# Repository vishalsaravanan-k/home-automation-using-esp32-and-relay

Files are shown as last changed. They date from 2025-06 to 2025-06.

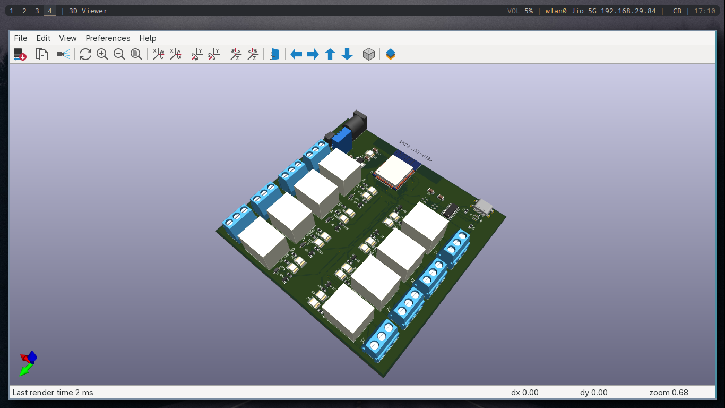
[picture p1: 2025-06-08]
Images/8.png

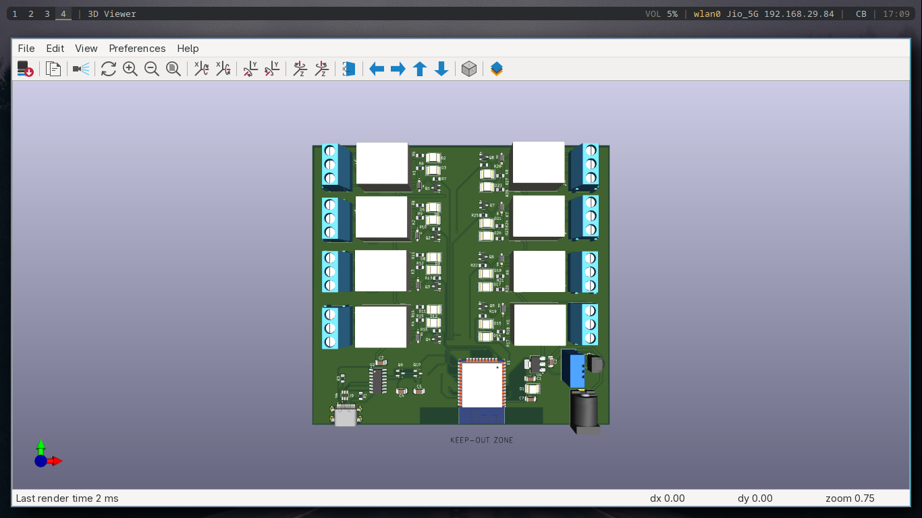
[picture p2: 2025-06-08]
Images/5.png

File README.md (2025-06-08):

# 🏠 Home Automation using ESP32 with relay

This project is a basic **home automation system** built using an **ESP32**, capable of turning appliances **ON/OFF** through both **mobile app (via Wi-Fi)** and an **IR remote**. It is designed for beginners in IoT and embedded systems who want to automate devices like lights, fans, or other home appliances.

---

## 📦 Features
- ✅ Control appliances via **Wi-Fi** (mobile app/web interface)
- ✅ Support for **IR remote control** using TSOP1838 sensor
- ✅ 8-channel relay circuit for switching multiple devices
- ✅ Designed using **KiCad** and built around **ESP32-WROOM-32**
- ✅ USB-C interface with ESD protection and CH340 serial converter
- ✅ Power supply using AMS1117-3.3

---

## 🧰 Hardware Components
- ESP32-WROOM-32
- CH340C (USB to serial)
- 8 x Relays (5V)
- 8 x BC547 Transistors
- Diodes (1N4007), LEDs, Resistors
- TSOP1838 IR Receiver
- USB-C Connector
- AMS1117-3.3 Voltage Regulator

---

## 🚀 How It Works
1. ESP32 receives **IR commands** from a remote via TSOP1838.
2. Or, it receives **commands over Wi-Fi** from a mobile/web app.
3. Based on the command, the ESP32 toggles one of the 8 relay channels.
4. Each relay can be connected to an AC appliance to turn it ON or OFF.

---

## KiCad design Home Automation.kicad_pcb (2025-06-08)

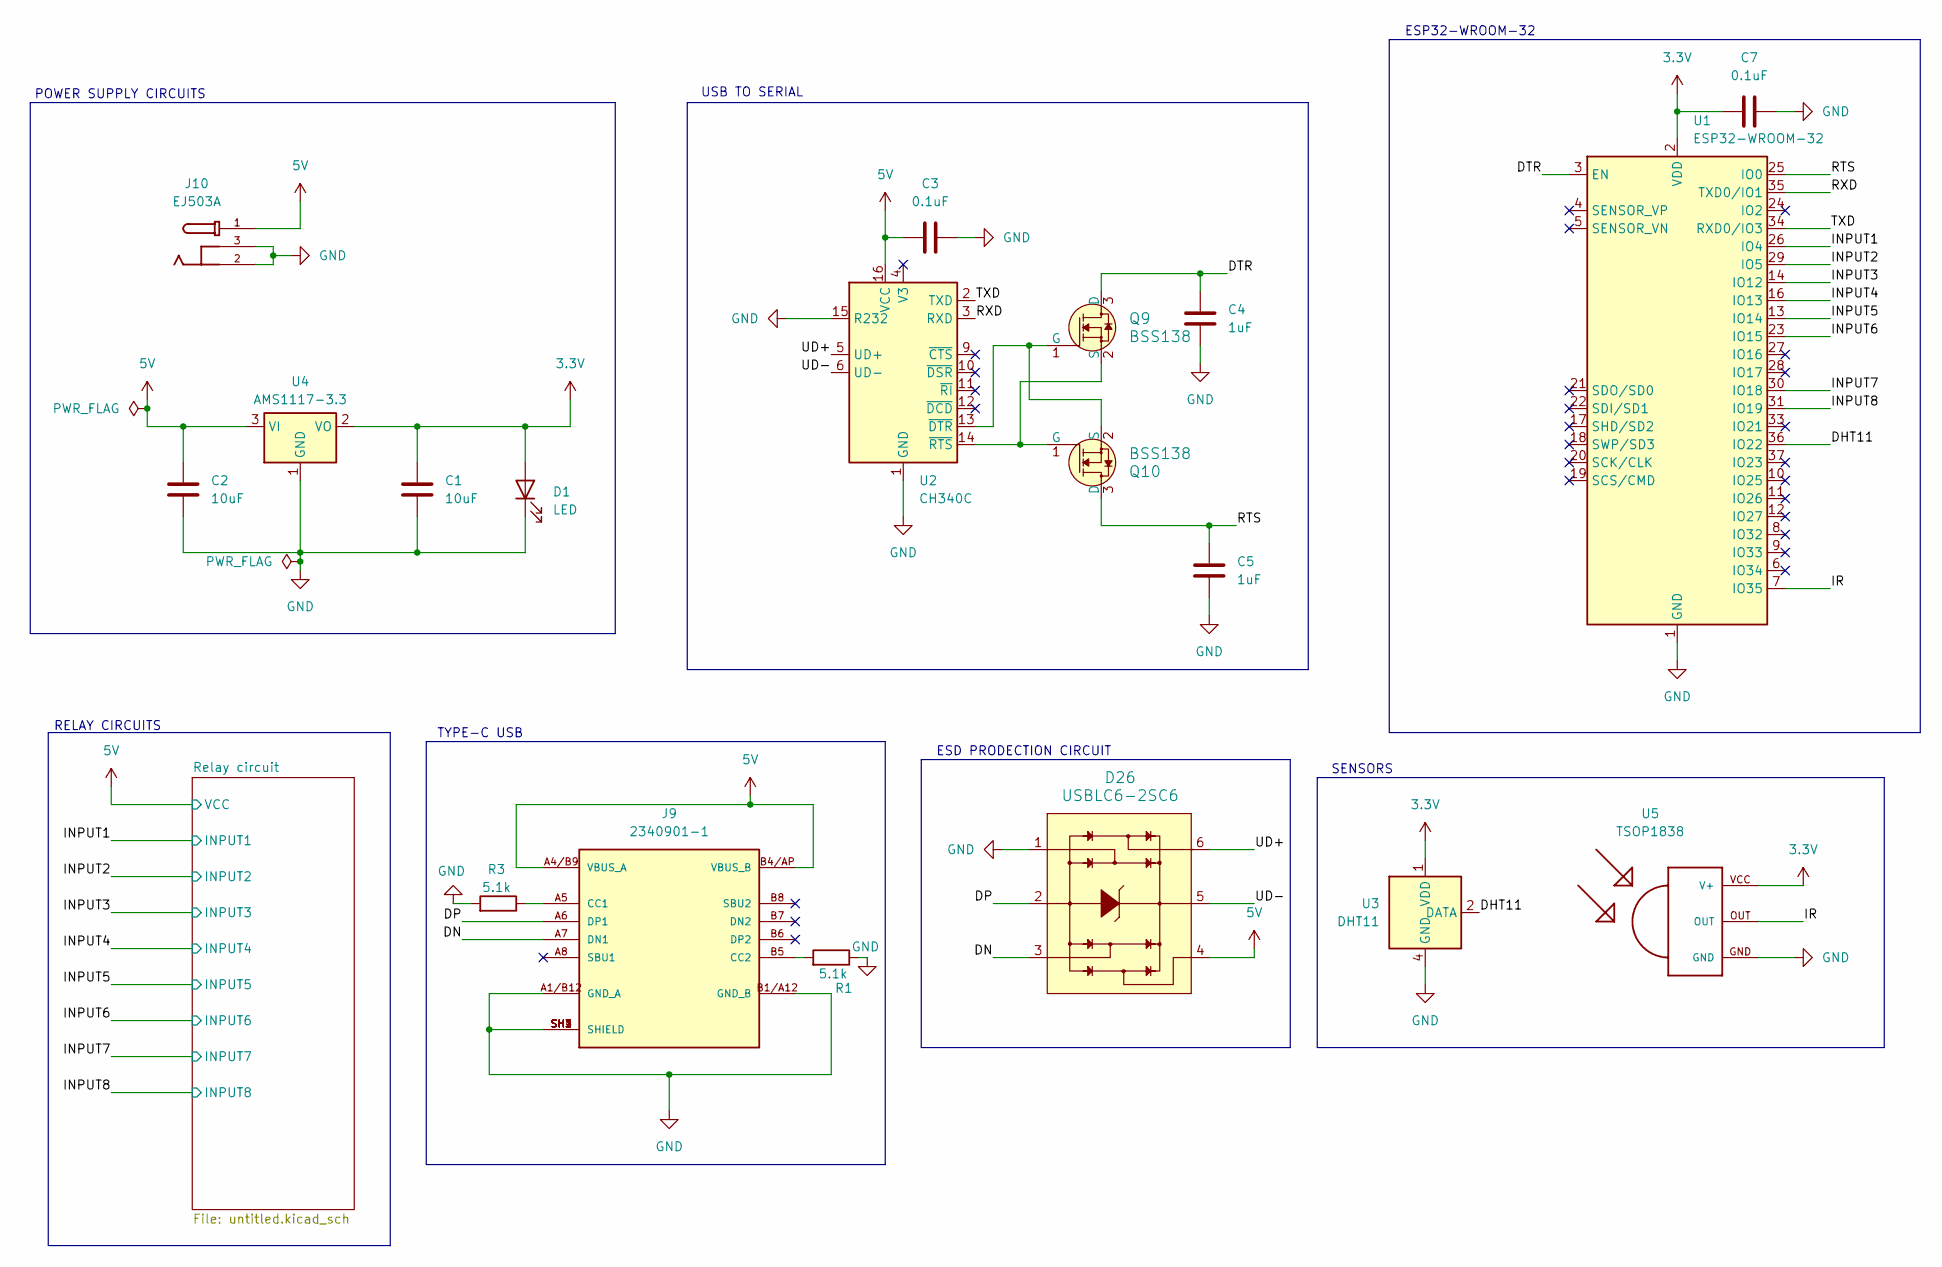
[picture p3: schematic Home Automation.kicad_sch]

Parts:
C1, C2: 10uF; C_1206_3216Metric_Pad1.33x1.80mm_HandSolder
C3, C7: 0.1uF; C_1206_3216Metric_Pad1.33x1.80mm_HandSolder
C4, C5: 1uF; C_1206_3216Metric_Pad1.33x1.80mm_HandSolder
D1: LED; LED_1812_4532Metric_Pad1.30x3.40mm_HandSolder
D26: USBLC6-2SC6; SOT95P280X145-6N; MPN USBLC6-2SC6; Digi-Key_PN 497-5235-1-ND
J9: 2340901-1; TE_2340901-1; PARTREV A
J10: EJ503A; MPD_EJ503A; PARTREV B
Q9, Q10: BSS138; SOT-23-3; MPN BSS138; Digi-Key_PN BSS138CT-ND
R1, R3: 5.1k; R_0805_2012Metric_Pad1.20x1.40mm_HandSolder
U1: ESP32-WROOM-32
U2: CH340C; SOIC-16_3.9x9.9mm_P1.27mm
U3: DHT11; Aosong_DHT11_5.5x12.0_P2.54mm
U4: AMS1117-3.3; SOT-223-3_TabPin2
U5: TSOP1838; TSOP18XX

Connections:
3.3V: C1.1, C7.1, D1.2 (A), U1.2 (VDD), U3.1 (VDD), U4.2 (VO), U5.VCC (V+)
5V: C2.1, C3.1, D26.4, J9.A4/B9 (VBUS_A), J9.B4/AP (VBUS_B), J10.1, U2.16 (VCC), U4.3 (VI); also elsewhere on the board
/DHT11: U1.36 (IO22), U3.2 (DATA)
/DN: D26.3, J9.A7 (DN1)
/DP: D26.2, J9.A6 (DP1)
/DTR: C4.2, Q9.3 (D), U1.3 (EN)
/INPUT1: U1.26 (IO4); also elsewhere on the board
/INPUT2: U1.29 (IO5); also elsewhere on the board
/INPUT3: U1.14 (IO12); also elsewhere on the board
/INPUT4: U1.16 (IO13); also elsewhere on the board
/INPUT5: U1.13 (IO14); also elsewhere on the board
/INPUT6: U1.23 (IO15); also elsewhere on the board
/INPUT7: U1.30 (IO18); also elsewhere on the board
/INPUT8: U1.31 (IO19); also elsewhere on the board
/IR: U1.7 (IO35), U5.OUT
/RTS: C5.2, Q10.3 (D), U1.25 (IO0)
/RXD: U1.35 (TXD0/IO1), U2.3 (RXD)
/TXD: U1.34 (RXD0/IO3), U2.2 (TXD)
/UD+: D26.6, U2.5 (UD+)
/UD-: D26.5, U2.6 (UD-)
GND: C1.2, C2.2, C3.2, C4.1, C5.1, C7.2, D1.1 (K), D26.1, J9.A1/B12 (GND_A), J9.B1/A12 (GND_B), J9.SH1 (SHIELD), J9.SH2 (SHIELD), J9.SH3 (SHIELD), J9.SH4 (SHIELD), J10.2, J10.3, R1.1, R3.2, U1.1 (GND), U1.15 (GND), U1.38 (GND), U1.39 (GND), U2.1 (GND), U2.15 (R232), U3.4 (GND), U4.1 (GND), U5.GND; also elsewhere on the board
unnamed: J9.A5 (CC1), R3.1
unnamed: J9.B5 (CC2), R1.2
unnamed: Q9.2 (S), Q10.1 (G), U2.14 (~RTS)
unnamed: Q9.1 (G), Q10.2 (S), U2.13 (~DTR)

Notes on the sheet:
SENSORS
ESD PRODECTION CIRCUIT
USB TO SERIAL
ESP32-WROOM-32
POWER SUPPLY CIRCUITS
TYPE-C USB
RELAY CIRCUITS

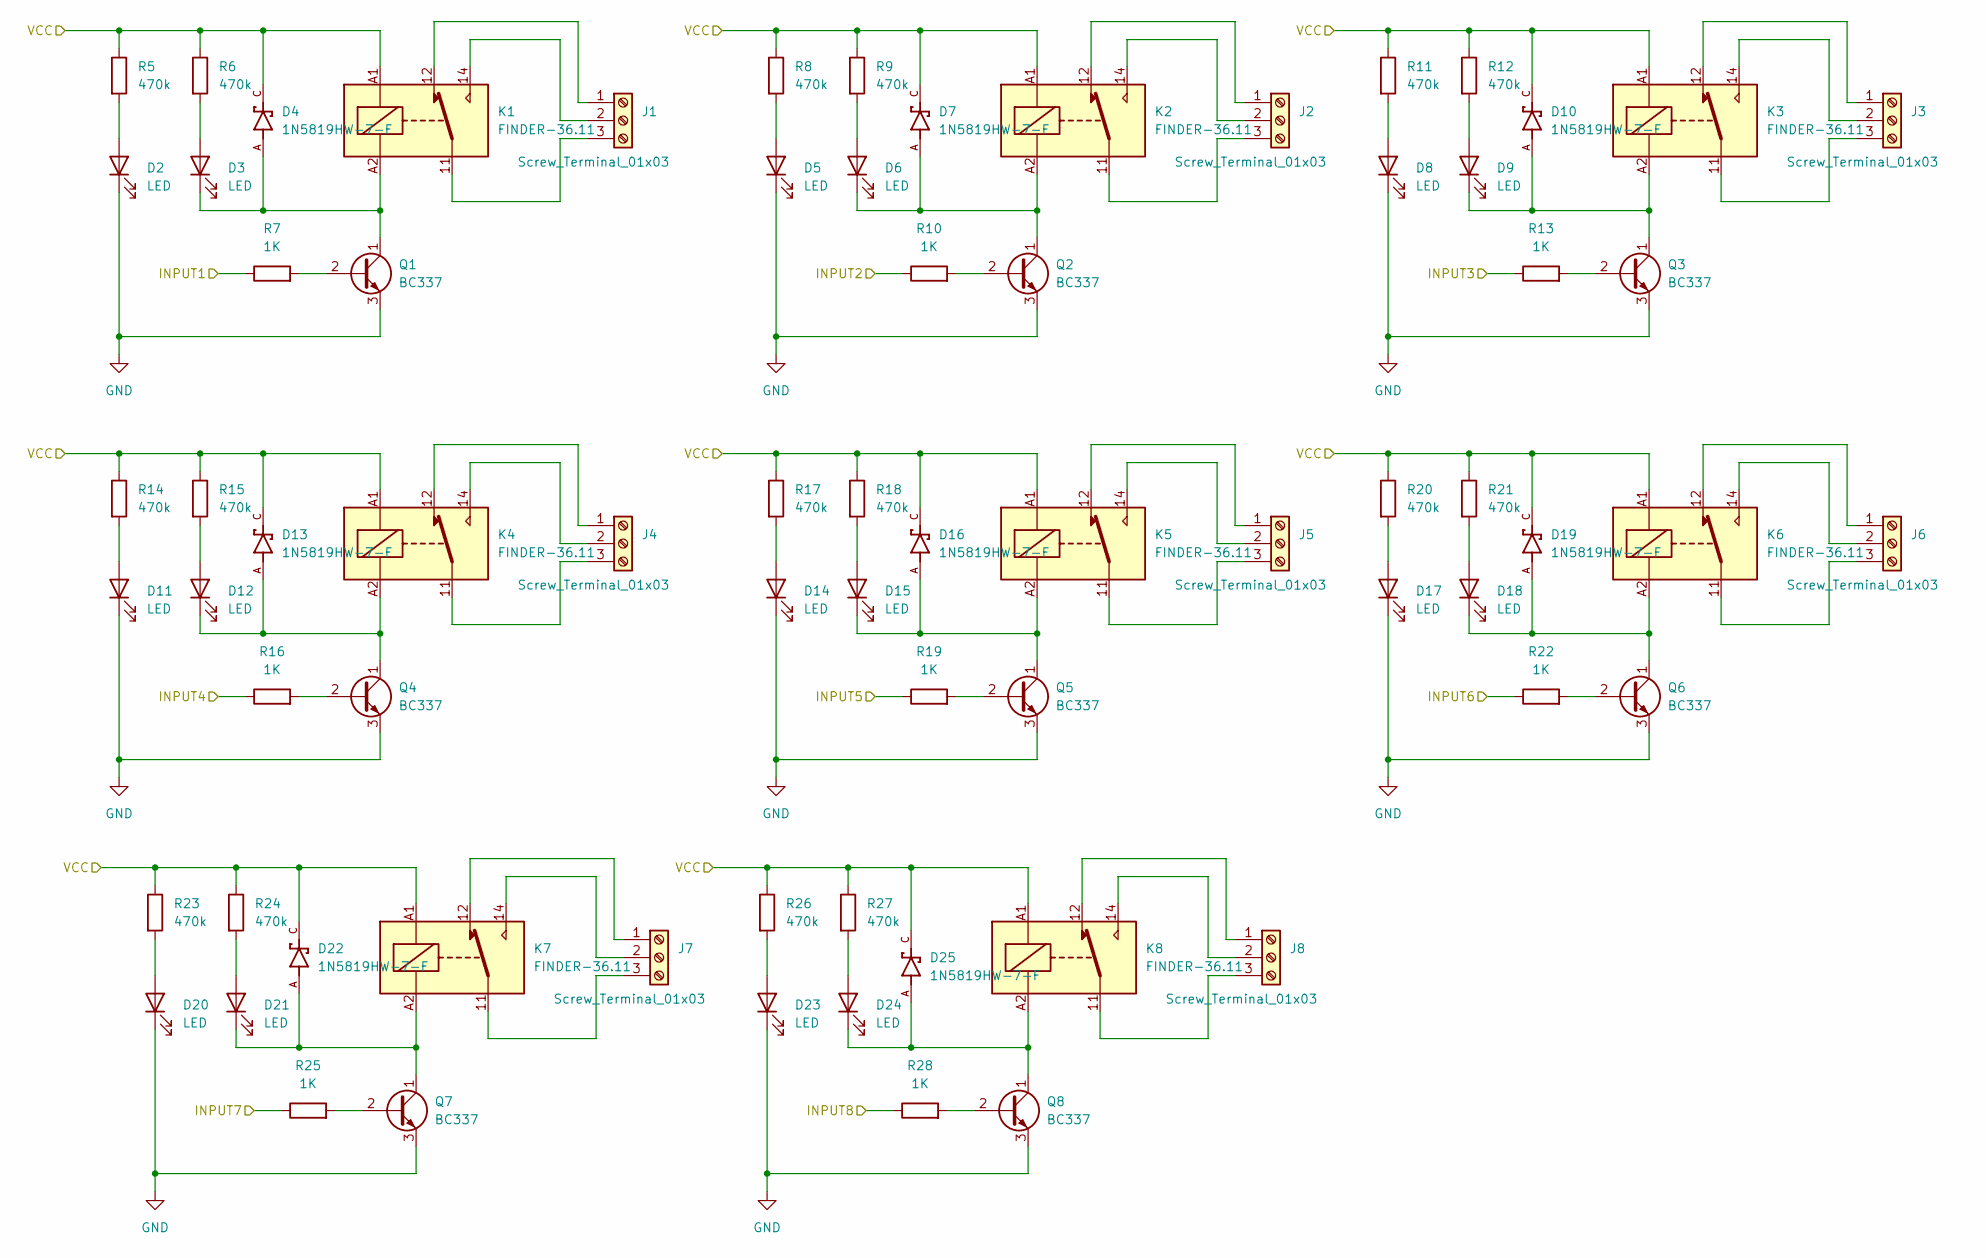
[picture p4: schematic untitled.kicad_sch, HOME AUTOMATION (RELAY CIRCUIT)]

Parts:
D2, D3, D5, D6, D8, D9, D11, D12, D14, D15, D17, D18, D20, D21, D23, D24: LED; LED_1812_4532Metric_Pad1.30x3.40mm_HandSolder
D4, D7, D10, D13, D16, D19, D22, D25: 1N5819HW-7-F; SOD3715X145N; PARTREV 18-2
J1, J2, J3, J4, J5, J6, J7, J8: Screw_Terminal_01x03; CUI_TB004-508-03BE
K1, K2, K3, K4, K5, K6, K7, K8: FINDER-36.11; Relay_SPDT_Finder_36.11
Q1, Q2, Q3, Q4, Q5, Q6, Q7, Q8: BC337; SOT-23-3
R5, R6, R8, R9, R11, R12, R14, R15, R17, R18, R20, R21, R23, R24, R26, R27: 470k; R_0805_2012Metric_Pad1.20x1.40mm_HandSolder
R7, R10, R13, R16, R19, R22, R25, R28: 1K; R_0805_2012Metric_Pad1.20x1.40mm_HandSolder

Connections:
5V: D4.C, D7.C, D10.C, D13.C, D16.C, D19.C, D22.C, D25.C, K1.A1, K2.A1, K3.A1, K4.A1, K5.A1, K6.A1, K7.A1, K8.A1, R5.1, R6.1, R8.1, R9.1, R11.1, R12.1, R14.1, R15.1, R17.1, R18.1, R20.1, R21.1, R23.1, R24.1, R26.1, R27.1; also elsewhere on the board
/INPUT1: R7.1; also elsewhere on the board
/INPUT2: R10.1; also elsewhere on the board
/INPUT3: R13.1; also elsewhere on the board
/INPUT4: R16.1; also elsewhere on the board
/INPUT5: R19.1; also elsewhere on the board
/INPUT6: R22.1; also elsewhere on the board
/INPUT7: R25.1; also elsewhere on the board
/INPUT8: R28.1; also elsewhere on the board
GND: D2.1 (K), D5.1 (K), D8.1 (K), D11.1 (K), D14.1 (K), D17.1 (K), D20.1 (K), D23.1 (K), Q1.3 (E), Q2.3 (E), Q3.3 (E), Q4.3 (E), Q5.3 (E), Q6.3 (E), Q7.3 (E), Q8.3 (E); also elsewhere on the board
unnamed: D2.2 (A), R5.2
unnamed: D3.2 (A), R6.2
unnamed: D3.1 (K), D4.A, K1.A2, Q1.1 (C)
unnamed: D5.2 (A), R8.2
unnamed: D6.2 (A), R9.2
unnamed: D6.1 (K), D7.A, K2.A2, Q2.1 (C)
unnamed: D8.2 (A), R11.2
unnamed: D9.2 (A), R12.2
unnamed: D9.1 (K), D10.A, K3.A2, Q3.1 (C)
unnamed: D11.2 (A), R14.2
unnamed: D12.2 (A), R15.2
unnamed: D12.1 (K), D13.A, K4.A2, Q4.1 (C)
unnamed: D14.2 (A), R17.2
unnamed: D15.2 (A), R18.2
unnamed: D15.1 (K), D16.A, K5.A2, Q5.1 (C)
unnamed: D17.2 (A), R20.2
unnamed: D18.2 (A), R21.2
unnamed: D18.1 (K), D19.A, K6.A2, Q6.1 (C)
unnamed: D20.2 (A), R23.2
unnamed: D21.2 (A), R24.2
unnamed: D21.1 (K), D22.A, K7.A2, Q7.1 (C)
unnamed: D23.2 (A), R26.2
unnamed: D24.2 (A), R27.2
unnamed: D24.1 (K), D25.A, K8.A2, Q8.1 (C)
unnamed: J1.1, K1.12
unnamed: J1.2, K1.14
unnamed: J1.3, K1.11
unnamed: J2.1, K2.12
unnamed: J2.2, K2.14
unnamed: J2.3, K2.11
unnamed: J3.1, K3.12
unnamed: J3.2, K3.14
unnamed: J3.3, K3.11
unnamed: J4.1, K4.12
unnamed: J4.2, K4.14
unnamed: J4.3, K4.11
unnamed: J5.1, K5.12
unnamed: J5.2, K5.14
unnamed: J5.3, K5.11
unnamed: J6.1, K6.12
unnamed: J6.2, K6.14
unnamed: J6.3, K6.11
unnamed: J7.1, K7.12
unnamed: J7.2, K7.14
unnamed: J7.3, K7.11
unnamed: J8.1, K8.12
unnamed: J8.2, K8.14
unnamed: J8.3, K8.11
unnamed: Q1.2 (B), R7.2
unnamed: Q2.2 (B), R10.2
unnamed: Q3.2 (B), R13.2
unnamed: Q4.2 (B), R16.2
unnamed: Q5.2 (B), R19.2
unnamed: Q6.2 (B), R22.2
unnamed: Q7.2 (B), R25.2
unnamed: Q8.2 (B), R28.2

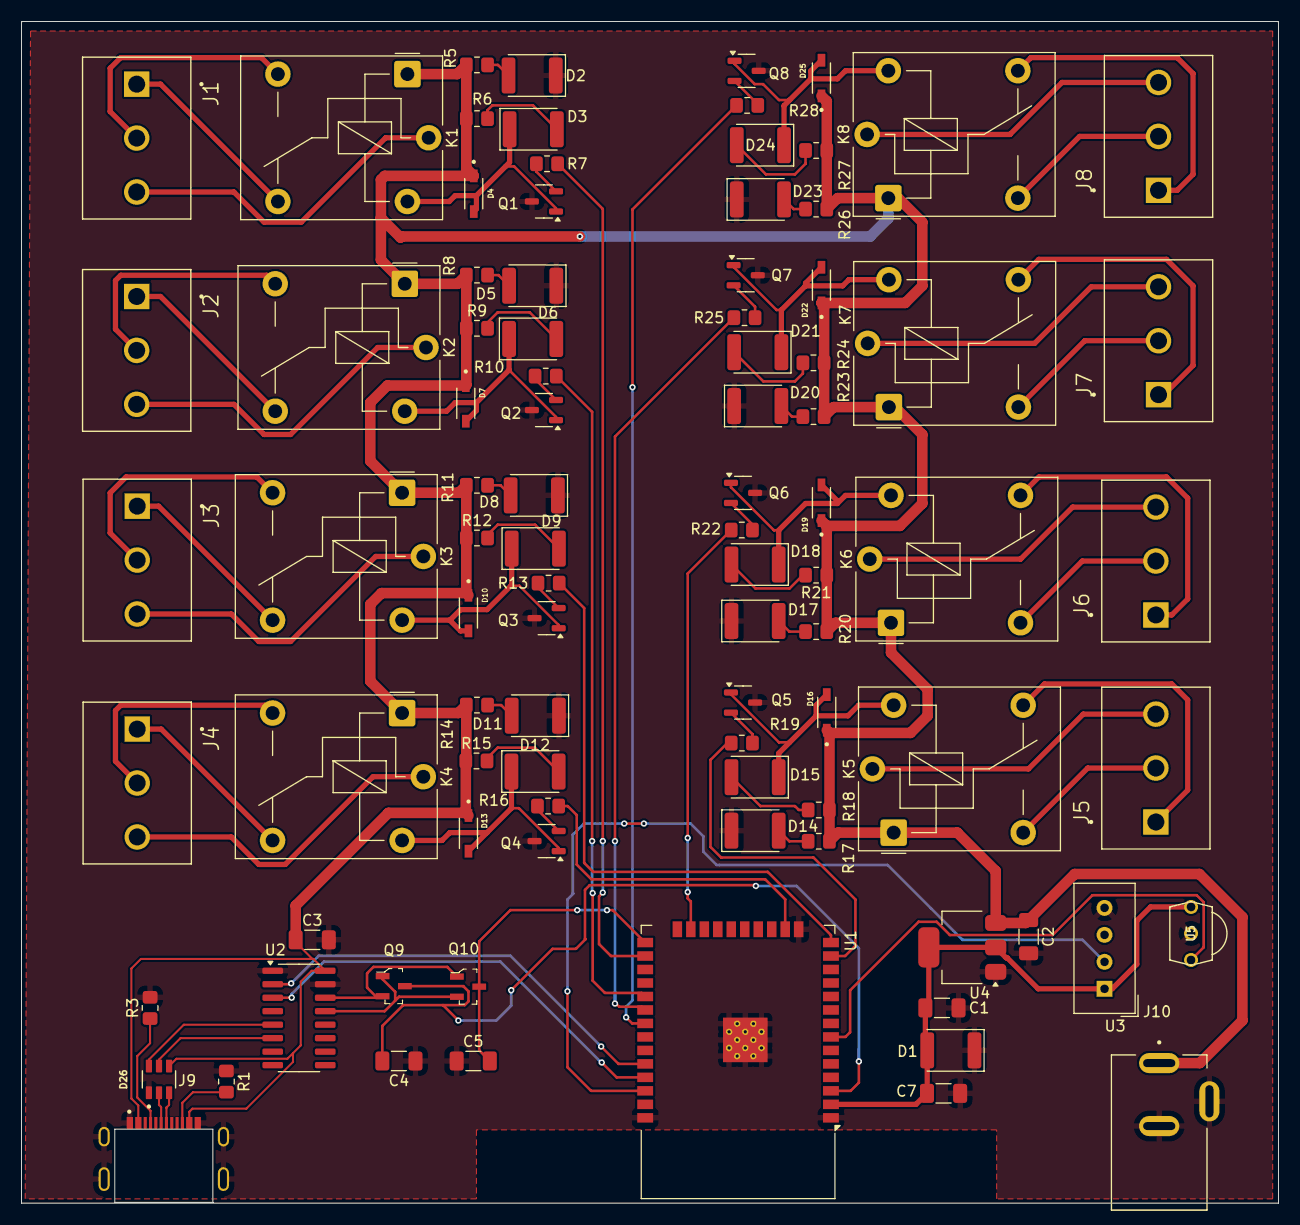
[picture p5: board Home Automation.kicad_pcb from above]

Board: 2 copper layers, 118.4 x 111.3 mm, 91 parts (0 on the bottom side), 81 nets.
